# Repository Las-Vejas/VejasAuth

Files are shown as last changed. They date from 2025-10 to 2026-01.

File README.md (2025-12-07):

# VejasAuth

This is a Yubikey clone/alternative to save passkeys. I mainly made it so I could have a passkey key for the computers at my school as writing passwords is annoying.

This auth key includes:
- The RP2350 microcontroller
- 128mbit storage
- 2 buttons
- 5 GPIO outputs
- a neopixel
- a USBC port
- a USBA port

Here are some pictures / renders of it!


SCR-20251013-rfij


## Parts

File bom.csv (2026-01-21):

BOM
JLCPCB BOM
Item | Price | NOTES
PCB | 4.10
Stencil | 3
Shipping | 14.68 | Cheapest option possible, also price is halved as it will be shared with another (or 2 other) project
LCSC BOM Quotation
Mrf# | Mfr. | Order Qty. | Unit Price(USD) | Ext.Price(USD) | LCSC# | Package | Description | Product Link
CL05A475MP5NRNC | Samsung Electro-Mechanics | 50 | 0.0049 | 0.25 | C23733 | 0402 | 4.7uF ±20% 10V Ceramic Capacitor X5R 0402 | https://www.lcsc.com/product-detail/C23733.html
CL05B104KO5NNNC | Samsung Electro-Mechanics | 100 | 0.0013 | 0.13 | C1525 | 0402 | 100nF ±10% 16V Ceramic Capacitor X7R 0402 | https://www.lcsc.com/product-detail/C1525.html
CL05C220JB5NNNC | Samsung Electro-Mechanics | 100 | 0.0027 | 0.27 | C70464 | 0402 | 22pF ±5% 50V Ceramic Capacitor C0G 0402 | https://www.lcsc.com/product-detail/C70464.html
CL10A106KP8NNNC | Samsung Electro-Mechanics | 50 | 0.0060 | 0.30 | C19702 | 0603 | 10uF ±10% 10V Ceramic Capacitor X5R 0603 | https://www.lcsc.com/product-detail/C19702.html
CL05A105KP5NNNC | Samsung Electro-Mechanics | 100 | 0.0018 | 0.18 | C14445 | 0402 | 1uF ±10% 10V Ceramic Capacitor X5R 0402 | https://www.lcsc.com/product-detail/C14445.html
WS2812B-2020 | Worldsemi | 10 | 0.0829 | 0.83 | C965555 | SMD,2.2x2mm | SMD,2.2x2mm LED Addressable, Specialty RoHS | https://www.lcsc.com/product-detail/C965555.html
TYPE-C 16PIN 2MD(073) | SHOU HAN | 20 | 0.0600 | 1.20 | C2765186 | SMD | USB-C (USB TYPE-C) Receptacle Connector 16 Position Surface Mount, Right Angle | https://www.lcsc.com/product-detail/C2765186.html
LQM21PN3R3MGRD | muRata | 10 | 0.0742 | 0.74 | C162585 | 0805 | 1A 3.3uH 187.5mΩ Multilayer inductor ±20% 0805 Fixed Inductors RoHS | https://www.lcsc.com/product-detail/C162585.html
RC0402FR-071KL | YAGEO | 100 | 0.0007 | 0.07 | C106235 | 0402 | 1kΩ 62.5mW 50V Thick Film Resistor ±100ppm/℃ ±1% 0402 Chip Resistor - Surface Mount RoHS | https://www.lcsc.com/product-detail/C106235.html
RC0402JR-075K1L | YAGEO | 100 | 0.0007 | 0.07 | C105873 | 0402 | 5.1kΩ ±5% 62.5mW 0402 Thick Film Resistor | https://www.lcsc.com/product-detail/C105873.html
RC0402JR-0727RL | YAGEO | 100 | 0.0007 | 0.07 | C137890 | 0402 | 27Ω 62.5mW 50V Thick Film Resistor ±100ppm/℃ ±5% 0402 Chip Resistor - Surface Mount RoHS | https://www.lcsc.com/product-detail/C137890.html
RC0402FR-0733RL | YAGEO | 100 | 0.0007 | 0.07 | C138002 | 0402 | 62.5mW 33Ω 50V Thick Film Resistor ±100ppm/℃ ±1% 0402 Chip Resistor - Surface Mount RoHS | https://www.lcsc.com/product-detail/C138002.html
SKRKAEE020 | ALPSALPINE | 10 | 0.1298 | 1.30 | C115357 | SMD,3.9x2.9mm | Tactile Switch SPST 2mm 3.9mm x 2.9mm Surface Mount | https://www.lcsc.com/product-detail/C115357.html
W25Q128JVSIQ | Winbond | 3 | 2.1253 | 6.38 | C97521 | SOIC-8-208mil | 2.7V~3.6V 128Mbit 133MHz SPI SOIC-8-208mil Memory (ICs) RoHS | https://www.lcsc.com/product-detail/C97521.html
XC6206P332MR-G | TOREX | 5 | 0.1033 | 0.52 | C5446 | SOT-23-3L | 6V Positive Fixed 3.3V SOT-23-3L Voltage Regulators - Linear, Low Drop Out (LDO) Regulators RoHS | https://www.lcsc.com/product-detail/C5446.html
RP2350A | Raspberry Pi | 3 | 1.2357 | 3.71 | C42411118 | QFN-60-EP(7x7) | QFN-60-EP(7x7) Microcontrollers RoHS | https://www.lcsc.com/product-detail/C42411118.html
ABM8-272-T3 | ABRACON | 5 | 0.3272 | 1.64 | C20625731 | SMD3225-4P | ±30ppm 10pF ±30ppm SMD3225-4P Crystals RoHS | https://www.lcsc.com/product-detail/C20625731.html
USB-05 | SOFNG | 5 | 0.0734 | 0.37 | C112454 | Through Hole | USB-A (USB TYPE-A) Receptacle Connector 4 Position Through Hole | https://www.lcsc.com/product-detail/C112454.html
TOTAL |  |  |  | 18.52
Shipping |  |  |  | 9.93 | Shared with another project.
TOTAL OF WHOLE BOM |  |  |  | 50.23

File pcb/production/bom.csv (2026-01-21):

Designator | Footprint | Quantity | Value | LCSC Part #
C1, C20, C21, C4 | 0402 | 4 | 4.7uF
C10, C11, C12, C13, C14, C2, C3, C5, C8, C9 | 0402 | 10 | 100nF
C16, C17 | 0402 | 2 | 22pF
C18, C19, C7 | 0603 | 3 | 10uF
C6 | 0402 | 1 | 1uF
D1 | LED_WS2812B-2020_PLCC4_2.0x2.0mm | 1 | WS2812B-2020
J2 | USB_C_Receptacle_GCT_USB4105-xx-A_16P_TopMnt_Horizontal | 1 | USB_C_Receptacle_USB2.0_16P
J3 | CUI_UP2-AH-4-TH | 1 | UP2-AH-4-TH
L1 | 0805 | 1 | 3.3u
R1, R3 | 0402 | 2 | 1k
R2, R7 | 0402 | 2 | 5.1k
R4, R5 | 0402 | 2 | 27
R6 | 0402 | 1 | 33
SW1, SW2 | SW_Push_SPST_NO_Alps_SKRK | 2 | SW_SPST
U2 | SOIC-8_5.3x5.3mm_P1.27mm | 1 | W25Q128JVS
U3 | SOT-23-3 | 1 | XC6206P332MR-G
U4 | QFN-60-1EP_7x7mm_P0.4mm_EP3.4x3.4mm_ThermalVias | 1 | RP2350A-QFN60
Y1 | Crystal_SMD_3225-4Pin_3.2x2.5mm | 1 | ABM8-272-T3

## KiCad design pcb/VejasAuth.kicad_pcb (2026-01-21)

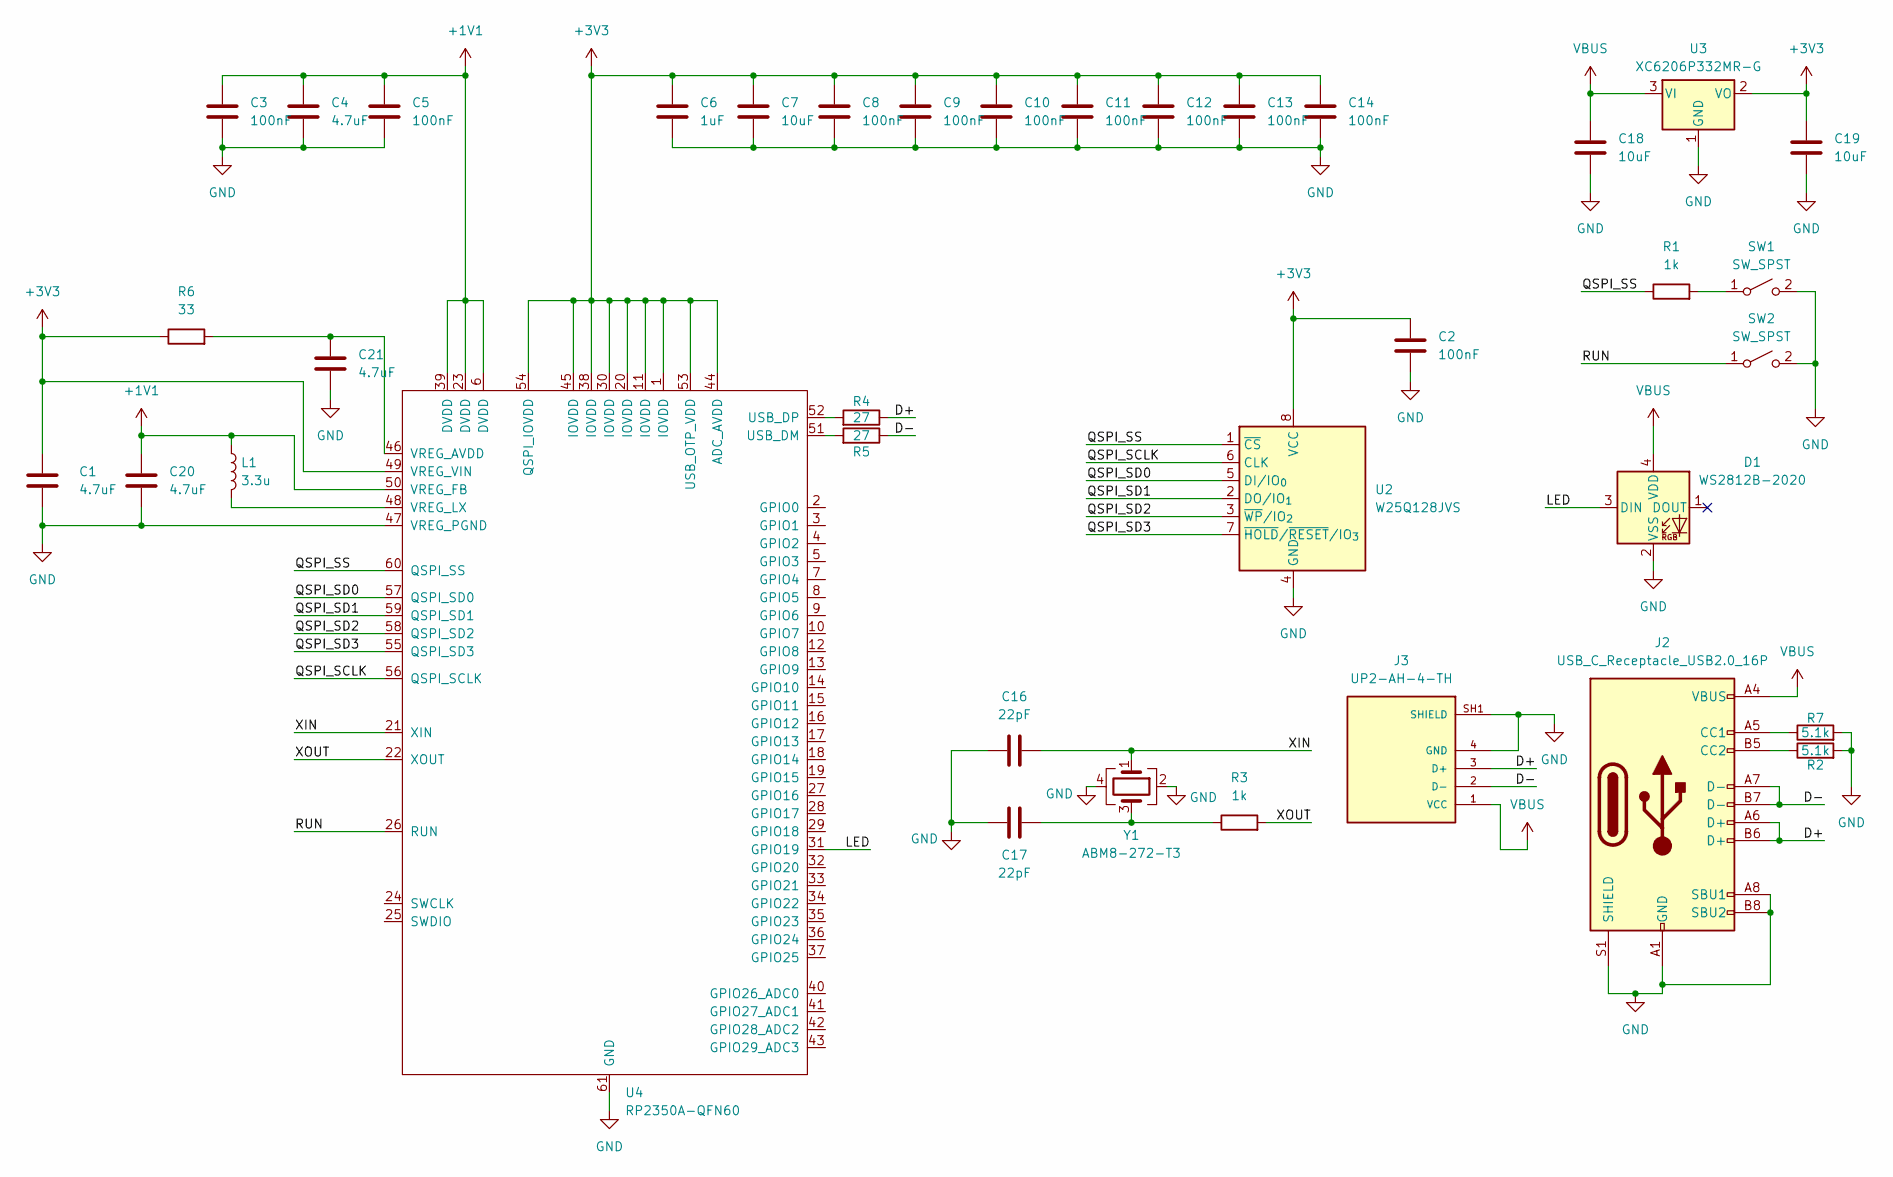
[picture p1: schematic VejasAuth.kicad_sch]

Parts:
C1, C4, C20, C21: 4.7uF; C_0402_1005Metric
C2, C3, C5, C8, C9, C10, C11, C12, C13, C14: 100nF; C_0402_1005Metric
C6: 1uF; C_0402_1005Metric
C7, C18, C19: 10uF; C_0603_1608Metric
C16, C17: 22pF; C_0402_1005Metric
D1: WS2812B-2020; LED_WS2812B-2020_PLCC4_2.0x2.0mm
J2: USB_C_Receptacle_USB2.0_16P; USB_C_Receptacle_GCT_USB4105-xx-A_16P_TopMnt_Horizontal
J3: UP2-AH-4-TH; CUI_UP2-AH-4-TH; PARTREV 1.05
L1: 3.3u; L_0805_2012Metric
R1, R3: 1k; R_0402_1005Metric
R2, R7: 5.1k; R_0402_1005Metric
R4, R5: 27; R_0402_1005Metric
R6: 33; R_0402_1005Metric
SW1, SW2: SW_SPST; SW_Push_SPST_NO_Alps_SKRK
U2: W25Q128JVS; SOIC-8_5.3x5.3mm_P1.27mm
U3: XC6206P332MR-G; SOT-23-3
U4: RP2350A-QFN60; QFN-60-1EP_7x7mm_P0.4mm_EP3.4x3.4mm_ThermalVias
Y1: ABM8-272-T3; Crystal_SMD_3225-4Pin_3.2x2.5mm

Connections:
+1V1: C3.1, C4.1, C5.1, C20.1, L1.1, U4.6 (DVDD), U4.23 (DVDD), U4.39 (DVDD), U4.50 (VREG_FB)
+3V3: C1.1, C2.1, C6.1, C7.1, C8.1, C9.1, C10.1, C11.1, C12.1, C13.1, C14.1, C19.1, R6.1, U2.8 (VCC), U3.2 (VO), U4.1 (IOVDD), U4.11 (IOVDD), U4.20 (IOVDD), U4.30 (IOVDD), U4.38 (IOVDD), U4.44 (ADC_AVDD), U4.45 (IOVDD), U4.49 (VREG_VIN), U4.53 (USB_OTP_VDD), U4.54 (QSPI_IOVDD)
/D+: J2.A6 (D+), J2.B6 (D+), J3.3 (D+), R4.1
/D-: J2.A7 (D-), J2.B7 (D-), J3.2 (D-), R5.1
/LED: D1.3 (DIN), U4.31 (GPIO19)
/QSPI_SCLK: U2.6 (CLK), U4.56 (QSPI_SCLK)
/QSPI_SD0: U2.5 (DI/IO_{0}), U4.57 (QSPI_SD0)
/QSPI_SD1: U2.2 (DO/IO_{1}), U4.59 (QSPI_SD1)
/QSPI_SD2: U2.3 (~WP/IO_{2}), U4.58 (QSPI_SD2)
/QSPI_SD3: U2.7 (~HOLD/~RESET/IO_{3}), U4.55 (QSPI_SD3)
/QSPI_SS: R1.1, U2.1 (~CS), U4.60 (QSPI_SS)
/RUN: SW2.1 (A), U4.26 (RUN)
/XIN: C16.2, U4.21 (XIN), Y1.1
/XOUT: R3.2, U4.22 (XOUT)
GND: C1.2, C2.2, C3.2, C4.2, C5.2, C6.2, C7.2, C8.2, C9.2, C10.2, C11.2, C12.2, C13.2, C14.2, C16.1, C17.1, C18.2, C19.2, C20.2, C21.2, D1.2 (VSS), J2.A1 (GND), J2.A8 (SBU1), J2.A12 (GND), J2.B1 (GND), J2.B8 (SBU2), J2.B12 (GND), J2.S1 (SHIELD), J3.4 (GND), J3.SH1 (SHIELD), J3.SH2 (SHIELD), R2.2, R7.2, SW1.2 (B), SW2.2 (B), U2.4 (GND), U3.1 (GND), U4.47 (VREG_PGND), U4.61 (GND), Y1.2, Y1.4
unnamed: C17.2, R3.1, Y1.3
unnamed: J2.A5 (CC1), R7.1
unnamed: J2.B5 (CC2), R2.1
unnamed: R1.2, SW1.1 (A)
unnamed: R5.2, U4.51 (USB_DM)
unnamed: R4.2, U4.52 (USB_DP)
unnamed: C21.1, R6.2, U4.46 (VREG_AVDD)
unnamed: L1.2, U4.48 (VREG_LX)
VBUS: C18.1, D1.4 (VDD), J2.A4 (VBUS), J2.A9 (VBUS), J2.B4 (VBUS), J2.B9 (VBUS), J3.1 (VCC), U3.3 (VI)

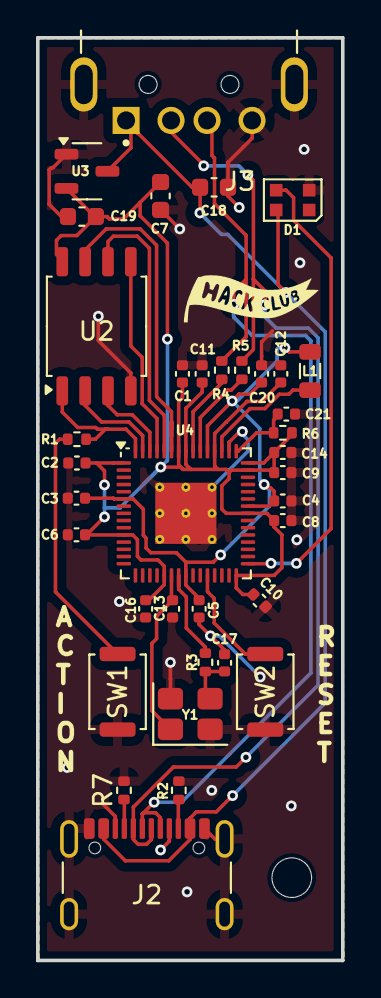
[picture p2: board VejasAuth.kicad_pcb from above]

Board: 2 copper layers, 16.9 x 51.3 mm, 37 parts (0 on the bottom side), 24 nets.

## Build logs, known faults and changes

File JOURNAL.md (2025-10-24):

<!--
  ===================    !!READ THIS NOTICE!!   ====================
  DO NOT edit this file manually. Your changes WILL BE OVERWRITTEN!
  This journal is auto generated and updated by Hack Club Blueprint.
  To edit this file, please edit your journal entries on Blueprint.
  ==================================================================
-->

## 10/12/2025 - Made the schematic  

So I started by (attempting) making the schematic with a guide by [@smartlinuxcoder](@https://github.com/smartlinuxcoder) and was using an rp2040 and the components he specified in his guide, but after asking a question in Slack I was met with the reality that the rp2040 is not safe enough for a yubikey.
So I started my journey with the RP2350. Thankfully I didn't have to erase a lot of my work, and only had to add/change a few things, and that's where I ran into problem number 2. 
I was faces by the pins of the RP2350's internal clock pins and I was bamboozled. so after many Slack messages and the reading of the hardware design guide, I figured out the layout of my schematic. My "piece de resistance" will be the dual usb option, as being a Mac user and having to deal with Windows PC's in school I have decided to put both a USB A and a USB C port on the thing.



## 10/13/2025 - Made the PCB  

I started by looking for parts and ways to actually solder this thing together. I found out that the may be a hotplate at the repair cafe in my school, so that's the way ill solder this thing rather than getting it PCBA from china (unless that's cheaper). Therefore I had to change the USBC port on the schematic and the PCB. So I did that, and I placed all my components on and routed everything.
Now I'll have to find every component in Digikey.

Here is my PCB:



## 10/19/2025 - Added an LED, and a hole for a keychain.  

So since the last update, I decided that an LED was necessary for this as I want to have some sort of physical confirmation after authentication. Also added some silkscreen.

To not lose my Auth thingy, I have also added a 2.2 mm hole in the bottom right corner which required me to move the USB C port to the left and I really did not want to do that as now my board is not symmetrical. :(

Also had to reroute a few things to reduce the size of the board so it's looking pretty nice!

Here's a picture of the layout of the usb c port. 


Silkscreen:


## 10/24/2025 - Exported Stuff and BOM  

I'm looking for things that are incorrect between my Digikey BOM and the one I have from kicad.
I found a capacitor missing a capacitance, And I found a resistor that is currently being a massive pain in my ass as I only found out it was missing when I finished routing ffs. 
So after that back to battling with the boms.
im getting close to double checking all the information and it should be done!



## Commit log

2025-10-24 cool stuff V1 i think
    [Sheet 1-VejasAuth from Digikey.csv, Sheet 1-VejasAuth-fromkicad.csv, VejasAuth.kicad_pcb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]
2026-01-21 big update
    [Sheet 1-VejasAuth from Digikey.csv, Sheet 1-VejasAuth-fromkicad.csv, VejasAuth.kicad_pcb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]
2026-01-21 upd bom
    [bom.csv]
